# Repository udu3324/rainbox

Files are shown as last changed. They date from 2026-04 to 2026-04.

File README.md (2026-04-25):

# Rainbox - Ambient Rain Sound Generator

render3

An ambient sound device that is designed to fit on your nightstand. It is based on the esp32 and is super hackable.

* Makes variable rain with different sounds
* Helps with sleep disorders (insomnia, etc.)
* Creates a mist
* Wi-Fi controllable

## Purpose

Rain is something relaxing to listen to, and being able to hear it at night brings a greater quality to sleep. Not only does this have more features than those small rain devices seen on temu, this actually makes rain that is more audible and realistic, as well as coming with a bunch of more features.

## Zine Page
Some details have been redacted. DM me for the full version!
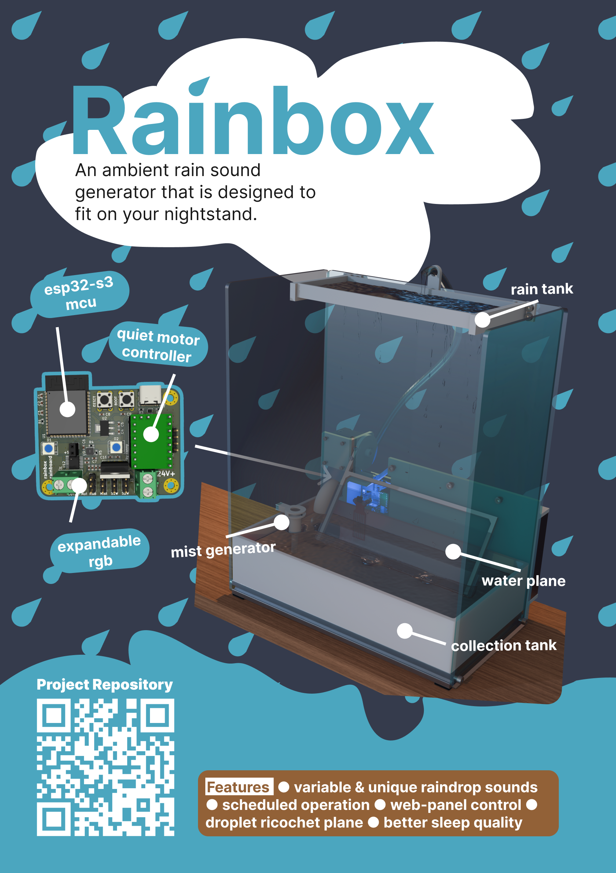
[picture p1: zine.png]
zine


## Webpanel Control

The Rainbox can be controlled through its webpanel that is hosted on its own AP or connected to WiFi.

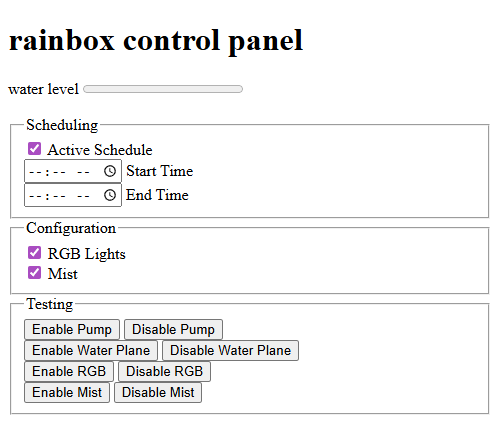
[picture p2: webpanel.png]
webpanel


## Mechanical Features

* Quiet submersed water pump that is speed controlled
* A water plane that makes water droplets ricochet off to make more unique noises
* Upper rain tank features hole diameters optimized for various water droplet sizes

### Stepper/Water Plane

A stepper motor directly controls the angle of a plastic/rubber sheet. It is a lightweight design that makes a alternative to where water droplets can land, and ultimately make more unique sounds. 

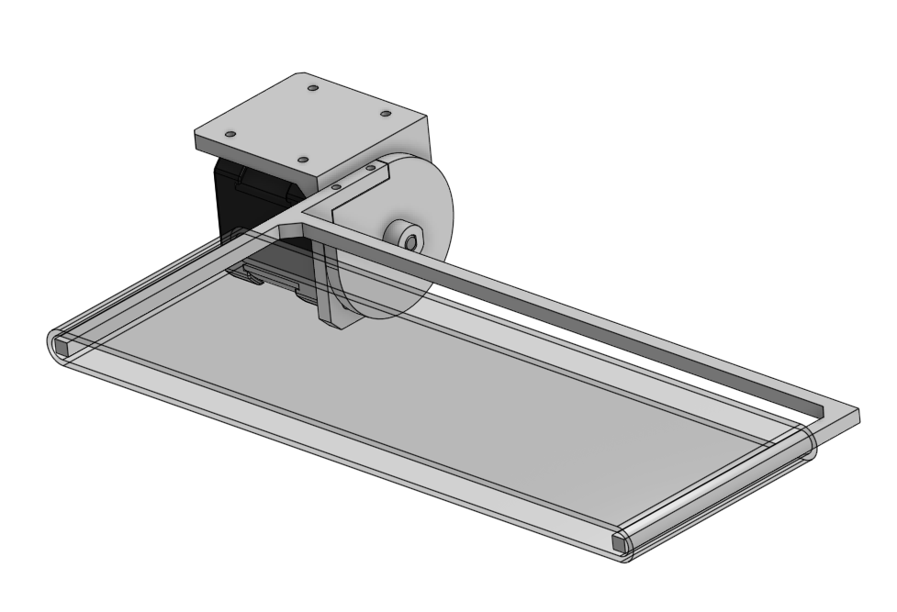
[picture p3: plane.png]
plane


### CAD

You can find the entire cad [here](https://cad.onshape.com/documents/e948a9a578129b2d9b3c44f2/w/f33f1e86b2b45cf8b68328c5/e/03b493761ac4f752afa24087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).

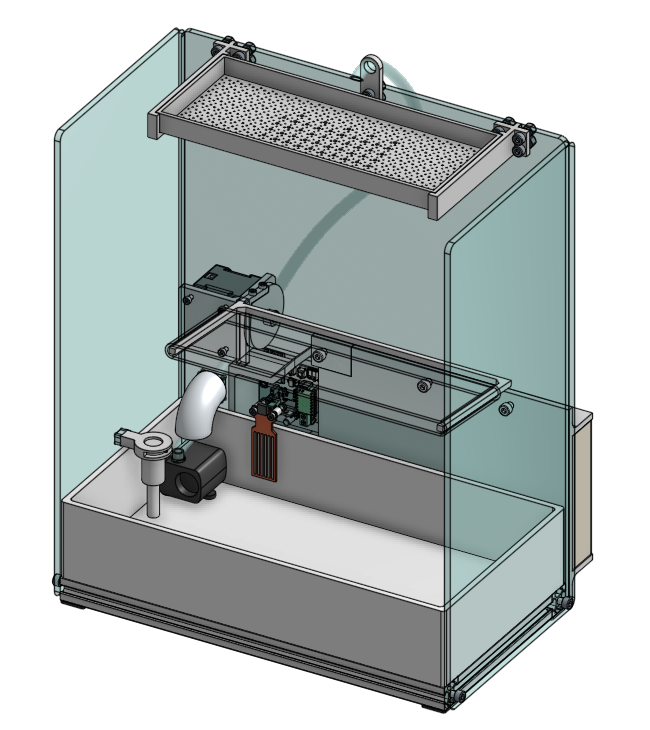
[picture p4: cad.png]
cad


## PCB Features

* Two RGB leds that can shine through the mist for ambience
* Can control a water atomizer to create mist
* Support for a external neopixel led strip
* Water level sensor support for closed loop control of the water pump
* TMC2240 stepper controller for StealthChop2™ support, making super quiet steps
* Super compact board with easy access to boot/reset buttons and usb-c

### Schematics

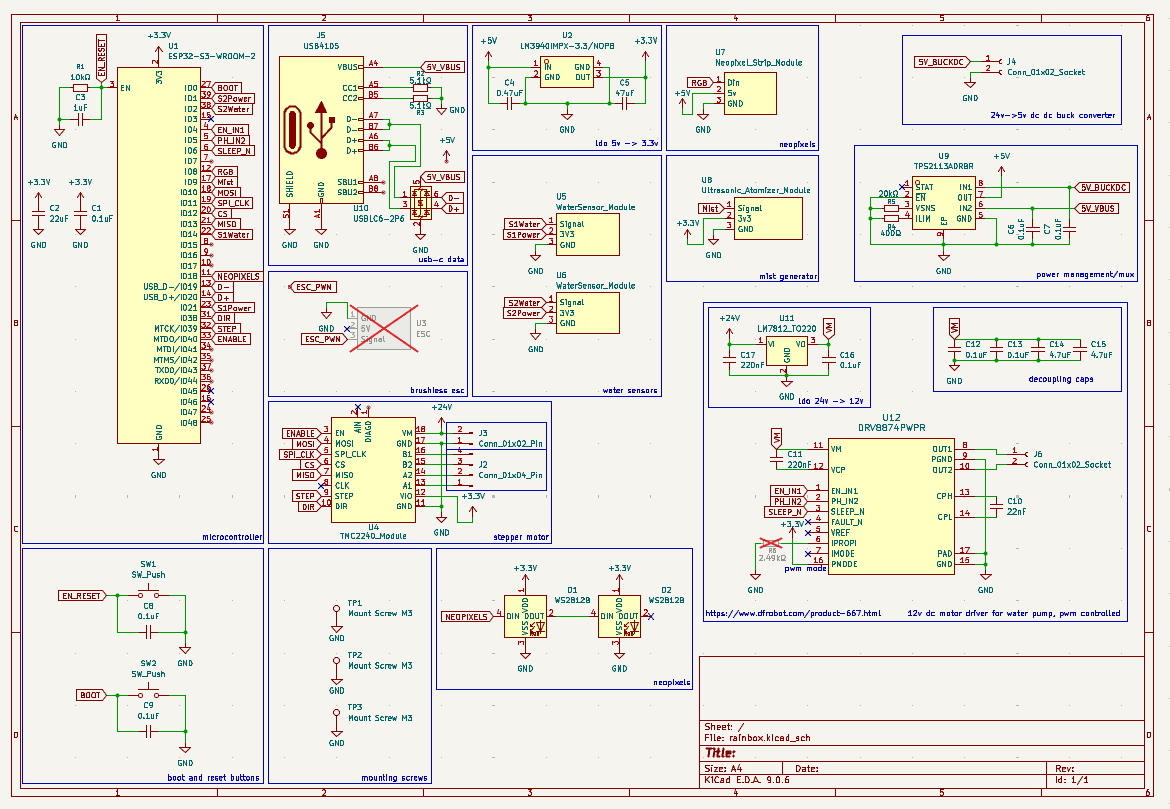
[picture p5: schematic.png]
schematic


### PCB

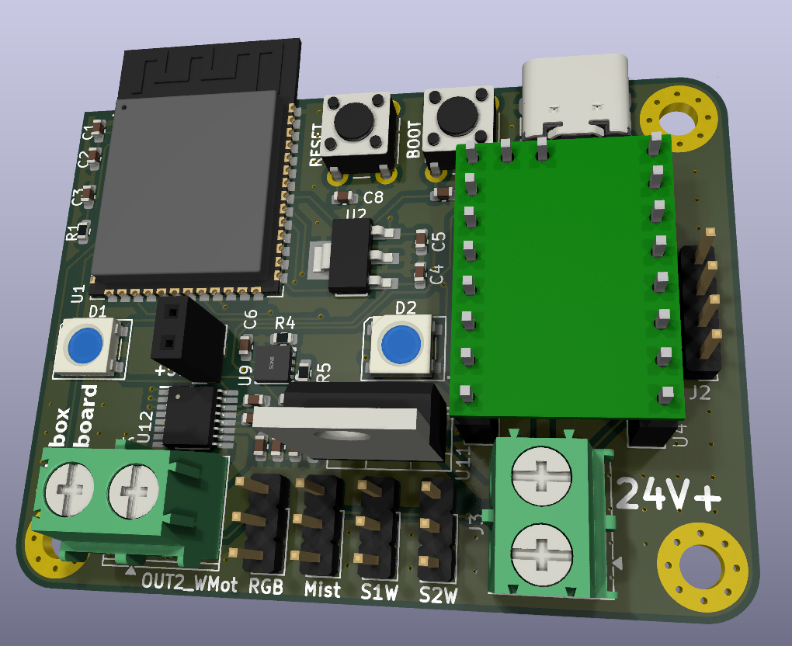
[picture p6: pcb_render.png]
pcb_render

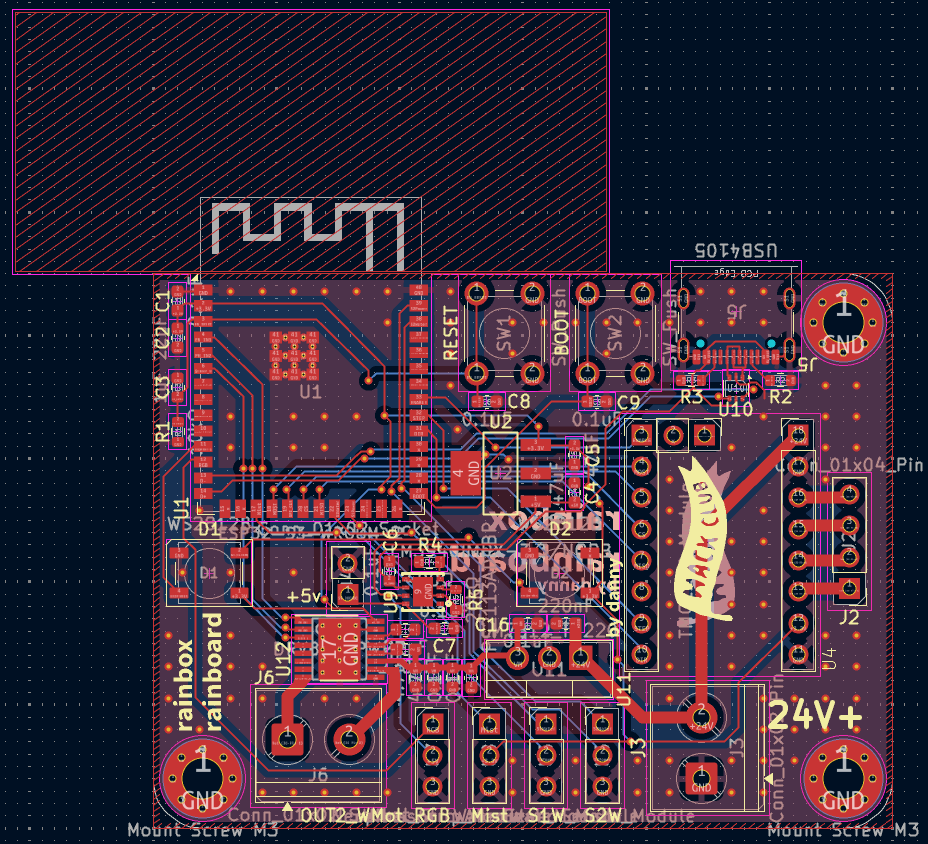
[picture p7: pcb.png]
pcb


## BOM

You can view the interactive BOM [here!](https://docs.google.com/spreadsheets/d/10gB80Lu2tYKqtstPC31-ZahqdRdbqbskEyKegbtCWHs/edit?usp=sharing) The total is around 150 USD.

### Build Steps
1. Get all the materials ready, 3d printed, and PCB fabricated
2. Cut out the polycarbonate on a CNC Mill
3. Tap the holes of the aluminum extrusion for M5 screws.
4. Assemble the bottom portion of the rainbox, which includes the bottom tank, aluminum extrusion, and polycarbonate walls
5. Screw the pcb onto the electronics cover
6. Connect all the motors, sensors, and water atomizer into the pcb
7. Mount all the electronics onto the back of the polycarbonate
8. Flash the firmware onto the board
9. Done! Control it through the WiFi AP web-panel

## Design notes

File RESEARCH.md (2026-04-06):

# rainbox research

## sound creation --- 

https://mynoise.net/NoiseMachines/rainNoiseGenerator.php
https://science.nasa.gov/earth/earth-observatory/listening-to-raindrops/

* water hitting directly on water (requires a depth of water)
* water hitting some sort of ground (tarp, or rubber)

### at what height? - 
water droplets hit their terminal velocity easily
~400mm

at what diameter of drop makes sound? what kind of sound? -
* 0.8/1.2mm dia - 13-25kHz direct water (high freq)
* 1.2/2.0 dia - quiet type
* 2.0/3.5mm dia - 1-10kHz direct water, 1-50kHz splat (low freq)

## fluid mechanics --- 

https://www.wisewell.com/blogs/news/is-deionized-water-the-same-as-distilled-water
use deionized water

focuses on creating these three diameter drops to create a dynamic sound of rain/weather

at least manage a ~2in deep water tank

water is brought from its bottom collecting tank to its upper tank, using a quiet motor with flaps 

based on the kohler rain shower head, a plate will guide water down holes using mainly gravity, not pressure

## electronics --- 

24v power supply

esp32-s3 (controls all)

### choice 1
https://zddcmotor.com/products/4245-brushless-motor (same)
https://www.aliexpress.us/item/3256807744943576.html
https://www.aliexpress.us/item/3256809335050730.html

### choice 2
https://www.underwaterthruster.com/products/3750-underwater-waterproof-and-corrosion-proof-brushless-motors-for-underwater-robots-and-rov-motors-for-unmanned-boats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
(get the esc from choice 1)
(also request them to waterproof/add cables free of charge)

brushless dc motor (preferably waterproof too but prioritize on quietness first)
brushless esc motor controller

nema 17 stepper motor
tmc2209/2240/2241 (prefer right to left) driver for quietness

https://www.aliexpress.us/item/3256806203259773.html
water level sensor (2x for top and bottom tank)

neopixel strip

https://www.aliexpress.us/item/3256809269681816.html
https://forum.arduino.cc/t/help-setting-25mm-ultrasonic-mist-maker/1333404
ultrasonic atomizer (m165d25, JHB20-17A384 or equivalent)
needs a driver controller of the same voltage and frequency

## frame/structure --- 

* tank/sides obviously has to be waterproof
* polycarbonate sides with a opening on one wall (maybe side cutouts too)
* bottom tank with a hole on the side, easy to clean and maintain
* 2020 aluminum extrusion for the frame and support
* petg prints preferred for everything
* petg or pvc flexible clear tubing

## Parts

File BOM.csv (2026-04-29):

Part | Description | URL | URL Note | Price (USD) (raw) | URL (Alt) | Price (Alt) (USD) | URL Note (Alt) | Quantity (per unit) | Sourcing | Subtotals
185x400 Polycarbonate | 5mm thick | https://clearambershop.com/en-us/products/axgard-clear-5mm-uv-protected-glazing-sheet | in the uk | 40.55 | https://www.lowes.com/pd/Professional-Plastics-Clear-Polycarbonate-Sheet-3-16TX48WX48L/7134359 | 78.9 | its double the size needed, cant find a smaller one :( | 2 | Need to buy | 78.9
330x400 Polycarb sheet | ~ | https://clearambershop.com/en-us/products/axgard-clear-5mm-uv-protected-glazing-sheet |  | 20 | not needed |  |  | 1 | Need to buy
330mm 2020 aluminum extrusion |  | https://www.zyltech.com/aluminum-extrusion-custom-cut-service/ |  | 2.26 |  |  |  | 2 | Already have | 4.52
140mm 2020 aluminum extrusion |  | ~ |  | 2.26 |  |  |  | 2 | Need to buy | 4.52
300x80mm Plastic/rubber sheet | i'll just upcycle some trash |  |  |  |  |  |  | 1 | Already have
Anti-slip rubber pad adhesive | 20x20mm squares | https://www.aliexpress.us/item/3256807696141646.html |  | 1 |  |  |  | 4 | Already have | 4
 |  |  |  |  |  |  |  |  |  | 91.94 | Frame Subtotal
Bottom (water) tank | 3d print (large) |  |  |  |  |  |  | 1 | Self-print
Surface fork holder | ~ |  |  |  |  |  |  | 1 | Self-print
Gear | ~ |  |  |  |  |  |  | 1 | Self-print
Tube guide | ~ |  |  |  |  |  |  | 1 | Self-print
Motor mount | ~ |  |  |  |  |  |  | 1 | Self-print
Power supply mount | ~ |  |  |  |  |  |  | 1 | Self-print
Electronics cover | ~ |  |  |  |  |  |  | 1 | Self-print
Water atomizer mount | ~ |  |  |  |  |  |  | 1 | Self-print
Rain tank | ~ (large) |  |  |  |  |  |  | 1 | Self-print
Rain tank holder | ~ |  |  |  |  |  |  | 1 | Self-print
Rain tank holder 2 | ~ |  |  |  |  |  |  | 1 | Self-print
Top tube holder | ~ |  |  |  |  |  |  | 1 | Self-print
Spacer | ~ |  |  |  |  |  |  | 2 | Self-print
 |  |  |  |  |  |  |  |  |  | 0 | 3D-Print Subtotal
Water sensor | generic | https://www.aliexpress.us/item/3256806203259773.html |  | 1.01 |  |  |  | 1 | Need to buy | 1.01
Water atomizer | includes wick & control board | https://www.aliexpress.us/item/3256809269681816.html |  | 1.3 |  |  |  | 1 | Need to buy | 1.3
Water pump (350L/H) | generic, includes tube | https://www.dfrobot.com/product-667.html |  | 9.2 |  |  |  | 1 | Need to buy | 9.2
Nema 17 40mm stepper motor | 4 pin 2.54 pitch | https://www.omc-stepperonline.com/nema-17-bipolar-0-9deg-36ncm-51oz-in-0-9a-5-4v-42x42x40mm-4-wires-17hm15-0904s |  | 12.05 |  |  |  | 1 | Already have | 12.05
AC Plug (inlet, 719W-UEL3BR51) | c13 | https://www.digikey.com/en/products/detail/qualtek/719W-UEL3BR51/23019206 |  | 6.7 |  |  |  | 1 | Already have | 6.7
C13 AC Power Cord | generic, monitor cable | ? |  |  |  |  |  | 1 | Already have
24v Power Supply | LRS-350-24 | https://meanwell-ps.com/products/lrs-350-24 |  | 31.4 |  |  |  | 1 | Already have | 31.4
 |  |  |  |  |  |  |  |  |  | 61.66 | Electronics Subtotal
M5x0.8x16mm cap screw | stainless steel, no rust | https://www.mcmaster.com/91292A126/ | packs of 100 | 14.86 | https://detail.tmall.com/item.htm?id=722759297726 | 1.14 |  | 23 | Need to buy | 1.14
M5x0.8 Nylon lock nut | ~ | https://www.mcmaster.com/94205A240/ | packs of 50 | 8 | https://detail.tmall.com/item.htm?id=556902193652 | 0.63 |  | 13 | Need to buy | 0.63
M4x0.7x8mm cap screw | ~ (for power supply mount) | https://www.mcmaster.com/91292A108/ | packs of 100 | 8.91 | https://detail.tmall.com/item.htm?id=722759297726 | 0.6 |  | 4 | Need to buy | 0.6
M3x0.5x16mm cap screw | ~ | https://www.mcmaster.com/91292A115/ | packs of 100 | 7.73 | ~ | 0.54 |  | 2 | Need to buy | 0.54
M3x0.5x12mm cap screw | ~ | https://www.mcmaster.com/91292A114/ | packs of 100 | 6.54 | ~ | 0.89 |  | 4 | Need to buy | 0.89
M3x0.5x8mm cap screw | ~ | https://www.mcmaster.com/91292A112/ | packs of 100 | 5.94 | ~ | 0.8 |  | 6 | Need to buy | 0.8
M3x0.5x6mm cap screw | ~ | https://www.mcmaster.com/91292A111/ | packs of 100 | 12.71 | ~ | 0.69 |  | 3 | Need to buy | 0.69
M3x0.5x4mm cap screw | ~ (for gear shaft lock) | https://www.mcmaster.com/91292A109/ | packs of 50 | 3.86 | ~ | 0.71 |  | 1 | Need to buy | 0.71
M3 nylon lock nuts | ~ (or thin ones) | https://www.mcmaster.com/94205A220/ | packs of 50 | 6.52 | https://detail.tmall.com/item.htm?id=556902193652 | 0.55 |  | 6 | Need to buy | 0.55
2020 frame T-slot nuts | generic | https://www.pcboard.ca/sliding-t-slot-nut | packs of 5 | 0.78 |  |  |  | 4 | Already have | 3.12
 |  |  |  |  |  |  |  |  |  | 9.67 | Fasteners Subtotal
TMC2240 Module | plugs into pcb | https://biqu.equipment/products/bigtreetech-tmc2240-v1-0 |  | 11 |  |  |  | 1 | Need to buy | 11
WS2182B | neopixel | https://www.digikey.com/en/products/detail/sparkfun-electronics/COM-24837/22321085 |  | 0.85 |  |  |  | 2 | Need to buy | 1.7
Screw Terminal Block | 5mm pitch | https://www.digikey.com/en/products/detail/phoenix-contact/1935161/568614 |  | 1.07 |  |  |  | 2 | Need to buy | 2.14
2 Row Pin Socket | 2.54 pitch | https://www.digikey.com/en/products/detail/preci-dip/801-87-002-10-001101/3757429 |  | 0.33 |  |  |  | 2 | Need to buy | 0.66
8 Row Pin Socket | ~ | https://www.digikey.com/en/products/detail/preci-dip/801-87-008-10-001101/3757440 |  | 1.04 |  |  |  | 2 | Need to buy | 2.08
3 Row Pin Header | ~ | https://www.digikey.com/en/products/detail/w%C3%BCrth-elektronik/61300311121/4846825 |  | 0.13 |  |  |  | 4 | Already have | 0.52
4 Row Pin Header | ~ | https://www.digikey.com/en/products/detail/w%C3%BCrth-elektronik/61300411121/4846827 |  | 0.19 |  |  |  | 1 | Already have | 0.19
6mm Tactile Switch Button |  | https://www.digikey.com/en/products/detail/schurter-inc/1301-9301/7602711 |  | 0.58 |  |  |  | 2 | Already have | 1.16
LM7812 | 24v to 12v | https://www.digikey.com/en/products/detail/texas-instruments/LM7812CT-NOPB/3901975 |  | 1.8 |  |  |  | 1 | Need to buy | 1.8
ESP32-S3-Wroom-2 |  | https://www.digikey.com/en/products/detail/espressif-systems/ESP32-S3-WROOM-2-N32R16V/25811280 |  | 11.44 |  |  |  | 1 | Need to buy | 11.44
0.1uF | 0603 ceramic capacitor | https://www.digikey.com/en/products/detail/murata-electronics/GRM033R60J104KE19D/702433 |  | 0.1 |  |  |  | 8 | Need to buy | 0.8
22nF | ~ | https://www.digikey.com/en/products/detail/samsung-electro-mechanics/CL10B223KO8WPNC/20498563 |  | 0.1 |  |  |  | 1 | Need to buy | 0.1
220nF | ~ | https://www.digikey.com/en/products/detail/samsung-electro-mechanics/CL10E224KA84PNC/20498501 |  | 0.17 |  |  |  | 2 | Need to buy | 0.34
4.7uF | ~ | https://www.digikey.com/en/products/detail/samsung-electro-mechanics/CL10A475KP8NNNC/3886702 |  | 0.1 |  |  |  | 2 | Need to buy | 0.2
22uF | ~ | https://www.digikey.com/en/products/detail/murata-electronics/GRM188R60G226MEA0D/2334877 |  | 0.13 |  |  |  | 1 | Need to buy | 0.13
1uF | ~ | https://www.digikey.com/en/products/detail/murata-electronics/GRM033R60J105MEA2D/4213369 |  | 0.1 |  |  |  | 1 | Need to buy | 0.1
0.47uF | ~ | https://www.digikey.com/en/products/detail/murata-electronics/GRM033R60J474KE90D/5027494 |  | 0.1 |  |  |  | 1 | Need to buy | 0.1
47uF | ~ | https://www.digikey.com/en/products/detail/murata-electronics/GRM188R60G476ME01D/13996897 |  | 0.35 |  |  |  | 1 | Need to buy | 0.35
USB4105 | usb c component | https://www.digikey.com/en/products/detail/gct/USB4105-GF-A/11198441 |  | 0.8 |  |  |  | 1 | Need to buy | 0.8
10kΩ | 0603 resistor | https://www.digikey.com/en/products/detail/yageo/RC0603FR-0710KL/726880 |  | 0.1 |  |  |  | 1 | Need to buy | 0.1
5.1kΩ | ~ | https://www.digikey.com/en/products/detail/yageo/RC0603FR-075K1L/727268 |  | 0.1 |  |  |  | 2 | Need to buy | 0.2
400Ω | ~ | https://www.digikey.com/en/products/detail/vishay-dale-thin-film/PAT0603E4000BST1/2278871 |  | 0.75 |  |  |  | 1 | Need to buy | 0.75
20kΩ | ~ | https://www.digikey.com/en/products/detail/yageo/RC0603FR-0720KL/727040 |  | 0.1 |  |  |  | 1 | Need to buy | 0.1
USBLC6-2P6 | usb esd protection ic | https://www.digikey.com/en/products/detail/stmicroelectronics/USBLC6-2P6/1007440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 |  | 0.65 |  |  |  | 1 | Need to buy | 0.65
DRV8874PWPR | dc motor controller | https://www.digikey.com/en/products/detail/texas-instruments/DRV8874PWPR/11502339 |  | 3.12 |  |  |  | 1 | Need to buy | 3.12
LM3940IMPX-3.3/NOPB | ldo 5v to 3v3 | https://www.digikey.com/en/products/detail/texas-instruments/LM3940IMPX-3-3-NOPB/367097 |  | 1.73 |  |  |  | 1 | Need to buy | 1.73
TPS2113ADRBR | power management ic | https://www.digikey.com/en/products/detail/texas-instruments/TPS2113ADRBR/2353703 |  | 2.35 |  |  |  | 1 | Need to buy | 2.35
 |  |  |  |  |  |  |  |  |  | 44.61 | Components Subtotal
PCB | JLCPCB PCB only service |  |  | 7.12 |  |  |  | 1 | Need to buy | 7.12
 |  |  |  |  |  |  |  |  |  | 7.12 | PCB Subtotal
 |  |  |  |  |  |  |  |  |  | 215 | TOTAL
 |  |  |  |  |  |  |  |  |  | 151 | TOTAL without things i already have

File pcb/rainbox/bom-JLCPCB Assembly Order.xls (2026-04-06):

JLCPCB BOM Tool - BOM Matching
BOM name：bom-JLCPCB Assembly Order.xlsx |  |  | Download Time：2026-04-05 12:07:02 |  |  |  | * Our matching results are updated in real-time, but stock and prices may change. If it's been over 24 hours, please re-match before placing your order.
PCB Assembled Qty：5 |  |  | Est. Total Price：12.9028
Your BOM |  |  |  |  | Matched Parts |  |  |  |  |  |  | Order Information
Top Designator | Bottom Designator | Comment | Footprint | JLCPCB Part # | Matches | Part # | Manufacturer | Footprint | Description | Category | Warning | JLCPCB Part # | Product link | Lib Type | Qty | Source | Total Price ($)
C1,C12,C13,C16,C6,C7,C8,C9 |  | 0.1uF | 0603 |  | Unconfirmed | CC0603KRX7R9BB104 | YAGEO | 0603 | 100nF 50V X7R ±10% 0603 Multilayer Ceramic Capacitors MLCC - SMD/SMT ROHS | Multilayer Ceramic Capacitors MLCC - SMD/SMT | 1.The comment (CC0603KRX7R9BB104) of this part does not match the one (0.1uF) provided in your BOM. Please confirm; | C14663 | https://jlcpcb.com/partdetail/YAGEO-CC0603KRX7R9BB104/C14663 | Basic | 16 | 16 JLCPCB | 0.0496
C2 |  | 22uF | 0603 |  | Select by System | CL10A226MQ8NRNC | Samsung Electro-Mechanics | 0603 | 22uF 6.3V X5R ±20% 0603 Multilayer Ceramic Capacitors MLCC - SMD/SMT ROHS | Multilayer Ceramic Capacitors MLCC - SMD/SMT |  | C59461 | https://jlcpcb.com/partdetail/60514-CL10A226MQ8NRNC/C59461 | Basic | 2 | 2 JLCPCB | 0.0188
C3 |  | 1uF | 0603 |  | Select by System | CL10A105KB8NNNC | Samsung Electro-Mechanics | 0603 | 1uF 50V X5R ±10% 0603 Multilayer Ceramic Capacitors MLCC - SMD/SMT ROHS | Multilayer Ceramic Capacitors MLCC - SMD/SMT |  | C15849 | https://jlcpcb.com/partdetail/16531-CL10A105KB8NNNC/C15849 | Basic | 2 | 2 JLCPCB | 0.0154
C4 |  | 0.47uF | 0603 |  | Unconfirmed | CL10B474KA8NNNC | Samsung Electro-Mechanics | 0603 | 25V 470nF X7R ±10% 0603 Multilayer Ceramic Capacitors MLCC - SMD/SMT ROHS | Multilayer Ceramic Capacitors MLCC - SMD/SMT | 1.The comment (CL10B474KA8NNNC) of this part does not match the one (0.47uF) provided in your BOM. Please confirm; | C1623 | https://jlcpcb.com/partdetail/1975-CL10B474KA8NNNC/C1623 | Basic | 2 | 2 JLCPCB | 0.013
C5 |  | 47uF | 0603 |  | Select by System | GRM188R60J476ME15D | Murata Electronics | 0603 | 47uF 6.3V X5R ±20% 0603 Multilayer Ceramic Capacitors MLCC - SMD/SMT ROHS | Multilayer Ceramic Capacitors MLCC - SMD/SMT |  | C140782 | https://jlcpcb.com/partdetail/152108-GRM188R60J476ME15D/C140782 | Extended | 6 | 6 JLCPCB | 0.3702
C10 |  | 22nF | 0603 |  | Select by System | CL10B223KB8NNNC | Samsung Electro-Mechanics | 0603 | 22nF 50V X7R ±10% 0603 Multilayer Ceramic Capacitors MLCC - SMD/SMT ROHS | Multilayer Ceramic Capacitors MLCC - SMD/SMT |  | C21122 | https://jlcpcb.com/partdetail/21834-CL10B223KB8NNNC/C21122 | Basic | 2 | 2 JLCPCB | 0.0084
C11,C17 |  | 220nF | 0603 |  | Select by System | CL10B224KA8NNNC | Samsung Electro-Mechanics | 0603 | 220nF 25V X7R ±10% 0603 Multilayer Ceramic Capacitors MLCC - SMD/SMT ROHS | Multilayer Ceramic Capacitors MLCC - SMD/SMT |  | C21120 | https://jlcpcb.com/partdetail/21832-CL10B224KA8NNNC/C21120 | Basic | 4 | 4 JLCPCB | 0.03
C14,C15 |  | 4.7uF | 0603 |  | Select by System | CL10A475KO8NNNC | Samsung Electro-Mechanics | 0603 | 16V 4.7uF X5R ±10% 0603 Multilayer Ceramic Capacitors MLCC - SMD/SMT ROHS | Multilayer Ceramic Capacitors MLCC - SMD/SMT |  | C19666 | https://jlcpcb.com/partdetail/20375-CL10A475KO8NNNC/C19666 | Basic | 4 | 4 JLCPCB | 0.0412
J5 |  | USB4105 | USB_C_Receptacle_GCT_USB4105-xx-A_16P_TopMnt_Horizontal |  | Select by System | USB4105-GF-A-060 | Global Connector Technology | SMD | -40℃~+85℃ 1 12P 48V 5A Black Female Surface Mount, Right Angle Type-C USB 2.0 SMD USB Connectors ROHS | USB Connectors |  | C3025063 | https://jlcpcb.com/partdetail/3554049-USB4105_GF_A060/C3025063 | Extended | 2 | 2 JLCPCB | 2.3648
R1 |  | 10kΩ | 0603 |  | Select by System | 0603WAF1002T5E | UNI-ROYAL(Uniroyal Elec) | 0603 | -55℃~+155℃ 100mW 10kΩ 75V Thick Film Resistor ±1% ±100ppm/℃ 0603 Chip Resistor - Surface Mount ROHS | Chip Resistor - Surface Mount |  | C25804 | https://jlcpcb.com/partdetail/26547-0603WAF1002T5E/C25804 | Basic | 2 | 2 JLCPCB | 0.0026
R2,R3 |  | 5.1kΩ | 0603 |  | Select by System | 0603WAF5101T5E | UNI-ROYAL(Uniroyal Elec) | 0603 | -55℃~+155℃ 100mW 5.1kΩ 75V Thick Film Resistor ±1% ±100ppm/℃ 0603 Chip Resistor - Surface Mount ROHS | Chip Resistor - Surface Mount |  | C23186 | https://jlcpcb.com/partdetail/23913-0603WAF5101T5E/C23186 | Basic | 4 | 4 JLCPCB | 0.0056
R4 |  | 400Ω | 0603 |  | Select by System | PAT0603E4000BST1 | Vishay Intertech | 0603 | -55℃~+155℃ 150mW 400Ω Thin Film Resistor ±0.1% ±25ppm/℃ 0603 Chip Resistor - Surface Mount ROHS | Chip Resistor - Surface Mount |  | C5841024 | https://jlcpcb.com/partdetail/VishayIntertech-PAT0603E4000BST1/C5841024 | Extended | 2 | 2 JLCPCB | 2.3806
R5 |  | 20kΩ | 0603 |  | Select by System | 0603WAF2002T5E | UNI-ROYAL(Uniroyal Elec) | 0603 | -55℃~+155℃ 100mW 20kΩ 75V Thick Film Resistor ±1% ±100ppm/℃ 0603 Chip Resistor - Surface Mount ROHS | Chip Resistor - Surface Mount |  | C4184 | https://jlcpcb.com/partdetail/4591-0603WAF2002T5E/C4184 | Basic | 2 | 2 JLCPCB | 0.0024
U2 |  | LM3940IMPX-3.3/NOPB | SOT-223-4_L6.5-W3.5-P2.30-LS7.0-BR |  | Select by System | LM3940IMPX-3.3/NOPB | Texas Instruments | SOT-223-4 | -40℃~+125℃ 1 110mA 150uVrms 1A 200mV@(100mA) 3.3V 7.5V Fixed Over Temperature Protection、Short Circuit Protection Positive SOT-223-4 Voltage Regulators - Linear, Low Drop Out (LDO) Regulators ROHS | Voltage Regulators - Linear, Low Drop Out (LDO) Regulators |  | C544820 | https://jlcpcb.com/partdetail/TexasInstruments-LM3940IMPX_3_3NOPB/C544820 | Extended | 2 | 2 JLCPCB | 2.761
U9 |  | TPS2113ADRBR | SON-8_L3.0-W3.0-P0.65-LS3.0-BL-EP |  | Select by System | TPS2113ADRBR | Texas Instruments | SON-8(3x3) | -40℃~+125℃ 2.8V~5.5V 2A 84mΩ Overcurrent Protection(OCP)、Over Temperature Protection SON-8(3x3) Power Distribution Switches ROHS | AC-DC Controllers And Regulators |  | C354512 | https://jlcpcb.com/partdetail/TexasInstruments-TPS2113ADRBR/C354512 | Extended | 2 | 2 JLCPCB | 1.8608
U10 |  | USBLC6-2P6 | SOT-666 |  | Select by System | USBLC6-2P6 | STMicroelectronics | SOT-666-6 | -40℃~+125℃ 150nA 17V 2 3.5pF 5.25V 5A@8/20us 6V ESD IEC 61000-4-2 Unidirectional SOT-666-6 ESD and Surge Protection (TVS/ESD) ROHS | ESD And Surge Protection (TVS/ESD) |  | C15999 | https://jlcpcb.com/partdetail/STMicroelectronics-USBLC62P6/C15999 | Extended | 5 | 5 JLCPCB | 1.219
U12 |  | DRV8874PWPR | PWP0016J_N |  | Select by System | DRV8874PWPR | Texas Instruments | HTSSOP-16-EP | -40℃~+125℃ 1 200mΩ 750nA 9A Yes HTSSOP-16-EP Brushed DC Motor Drivers ROHS | Brushed DC Motor Drivers |  | C1855818 | https://jlcpcb.com/partdetail/TexasInstruments-DRV8874PWPR/C1855818 | Extended | 2 | 2 JLCPCB | 1.7594
U1 |  | ESP32-S3-WROOM-2 | ESP32-S3-WROOM-2 |  | Unconfirmed | ESP32-S3-WROOM-2-N32R16V | Espressif Systems | SMD | -103.5dBm -40℃~+65℃ 2.4GHz 20.5dBm 355mA 3V~3.6V 95mA Bluetooth5.0 ESP32-S3R16V On-board PCB Antenna UART、SDIO、SPI、I2C、I2S、USB SMD WiFi Modules ROHS | WiFi Modules | 1.The comment (ESP32-S3-WROOM-2-N32R16V) of this part does not match the one (ESP32-S3-WROOM-2) provided in your BOM. Please confirm; | C42417293 | https://jlcpcb.com/partdetail/44421476-ESP32_S3_WROOM_2N32R16V/C42417293 | Extended | 2 | 0 JLCPCB | 0
D1,D2 |  | WS2812B | LED_WS2812B_PLCC4_5.0x5.0mm_P3.2mm |  | Unconfirmed | WS2812B-B/W |  |  | 0.6mA 1.57mm 2kHz 3.7V~5.3V 5.4mm 5mm 800Kbit/s B:465nm~475nm、R:620nm~630nm、G:515nm~525nm G:600mcd~1000mcd、B:200mcd~300mcd、R:300mcd~500mcd 内置上电复位电路、内置掉电复位电路、内置单向传输功能 SMD5050-4P RGB LEDs(Built-in IC) ROHS |  | 1.The comment (WS2812B-B/W) of this part does not match the one (WS2812B) provided in your BOM. Please confirm; |  |  | Extended | 0 | 0 JLCPCB | 0
J2 |  | Conn_01x04_Pin | PinHeader_1x04_P2.54mm_Vertical |  | No matches | No Part Selected
J3 |  | Conn_01x02_Pin | TerminalBlock_Phoenix_PT-1,5-2-5.0-H_1x02_P5.00mm_Horizontal |  | No matches | No Part Selected
J4 |  | Conn_01x02_Socket | PinSocket_1x02_P2.54mm_Vertical |  | No matches | No Part Selected
J6 |  | Conn_01x02_Socket | TerminalBlock_Phoenix_PT-1,5-2-5.0-H_1x02_P5.00mm_Horizontal |  | No matches | No Part Selected
SW1,SW2 |  | SW_Push | SW_PUSH_6mm |  | No matches | No Part Selected
U4 |  | TMC2240_Module | tmc2240_module |  | No matches | No Part Selected
U5,U6 |  | WaterSensor_Module | PinHeader_1x03_P2.54mm_Vertical |  | No matches | No Part Selected
U7 |  | Neopixel_Strip_Module | PinHeader_1x03_P2.54mm_Vertical |  | No matches | No Part Selected
U8 |  | Ultrasonic_Atomizer_Module | PinHeader_1x03_P2.54mm_Vertical |  | No matches | No Part Selected
U11 |  | LM7812_TO220 | TO-220-3_Vertical |  | No matches | No Part Selected

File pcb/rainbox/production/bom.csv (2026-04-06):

Designator | Footprint | Quantity | Value | LCSC Part #
C1, C12, C13, C16, C6, C7, C8, C9 | 0603 | 8 | 0.1uF
C10 | 0603 | 1 | 22nF
C11, C17 | 0603 | 2 | 220nF
C14, C15 | 0603 | 2 | 4.7uF
C2 | 0603 | 1 | 22uF
C3 | 0603 | 1 | 1uF
C4 | 0603 | 1 | 0.47uF
C5 | 0603 | 1 | 47uF
D1, D2 | LED_WS2812B_PLCC4_5.0x5.0mm_P3.2mm | 2 | WS2812B
J2 | PinHeader_1x04_P2.54mm_Vertical | 1 | Conn_01x04_Pin
J3 | TerminalBlock_Phoenix_PT-1,5-2-5.0-H_1x02_P5.00mm_Horizontal | 1 | Conn_01x02_Pin
J4 | PinSocket_1x02_P2.54mm_Vertical | 1 | Conn_01x02_Socket
J5 | USB_C_Receptacle_GCT_USB4105-xx-A_16P_TopMnt_Horizontal | 1 | USB4105
J6 | TerminalBlock_Phoenix_PT-1,5-2-5.0-H_1x02_P5.00mm_Horizontal | 1 | Conn_01x02_Socket
R1 | 0603 | 1 | 10kΩ
R2, R3 | 0603 | 2 | 5.1kΩ
R4 | 0603 | 1 | 400Ω
R5 | 0603 | 1 | 20kΩ
SW1, SW2 | SW_PUSH_6mm | 2 | SW_Push
TP1, TP2, TP3 | MountingHole_3.2mm_M3_Pad_Via | 3 | Mount Screw M3
U1 | ESP32-S3-WROOM-2 | 1 | ESP32-S3-WROOM-2
U10 | SOT-666 | 1 | USBLC6-2P6
U11 | TO-220-3_Vertical | 1 | LM7812_TO220
U12 | PWP0016J_N | 1 | DRV8874PWPR
U2 | SOT-223-4_L6.5-W3.5-P2.30-LS7.0-BR | 1 | LM3940IMPX-3.3/NOPB | C544820
U4 | tmc2240_module | 1 | TMC2240_Module
U5, U6 | PinHeader_1x03_P2.54mm_Vertical | 2 | WaterSensor_Module
U7 | PinHeader_1x03_P2.54mm_Vertical | 1 | Neopixel_Strip_Module
U8 | PinHeader_1x03_P2.54mm_Vertical | 1 | Ultrasonic_Atomizer_Module
U9 | SON-8_L3.0-W3.0-P0.65-LS3.0-BL-EP | 1 | TPS2113ADRBR | C354512

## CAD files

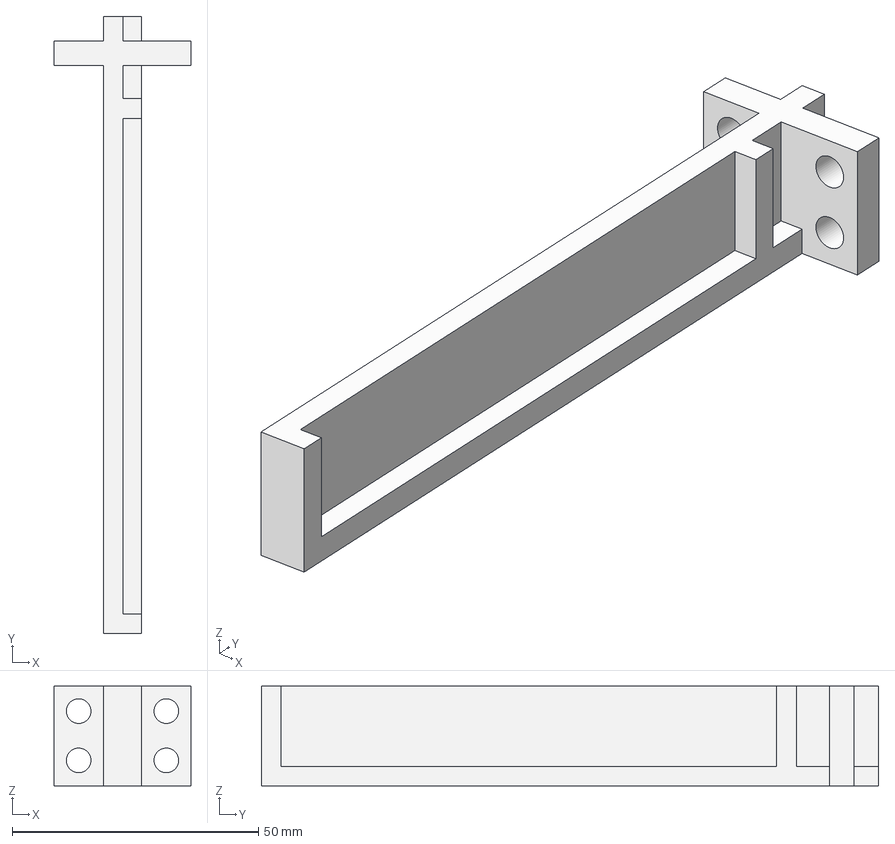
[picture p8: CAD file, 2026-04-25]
cad/Full Assembly - Rain Tank Holder.step
27.8 x 125.3 x 20.3 mm

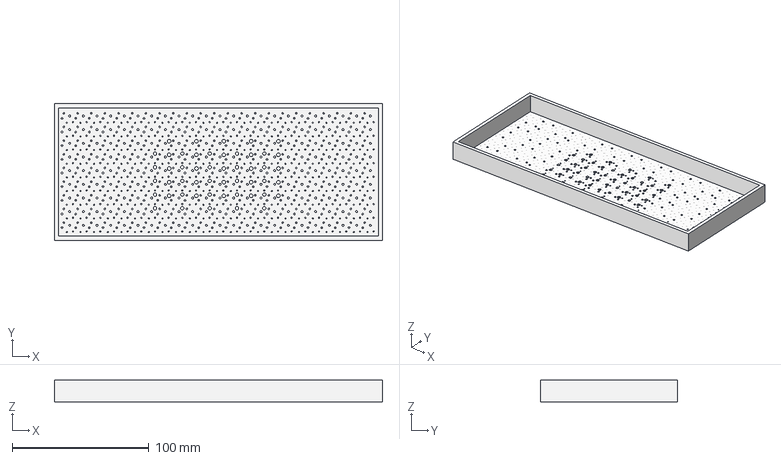
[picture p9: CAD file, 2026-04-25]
cad/Full Assembly - Rain Tank.step
240.0 x 100.0 x 16.0 mm

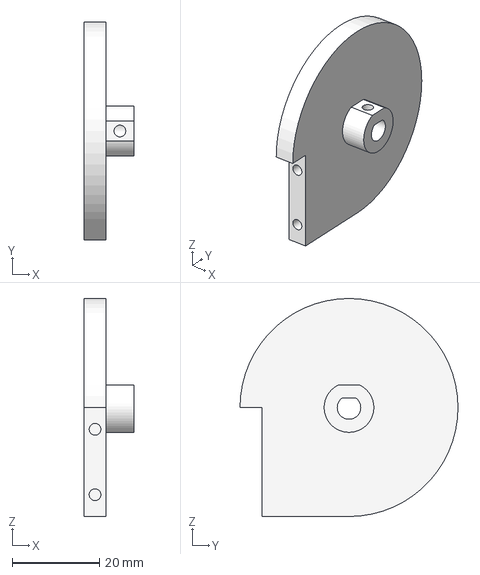
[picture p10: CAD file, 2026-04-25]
cad/Full Assembly - Gear.step
11.4 x 50.0 x 50.0 mm

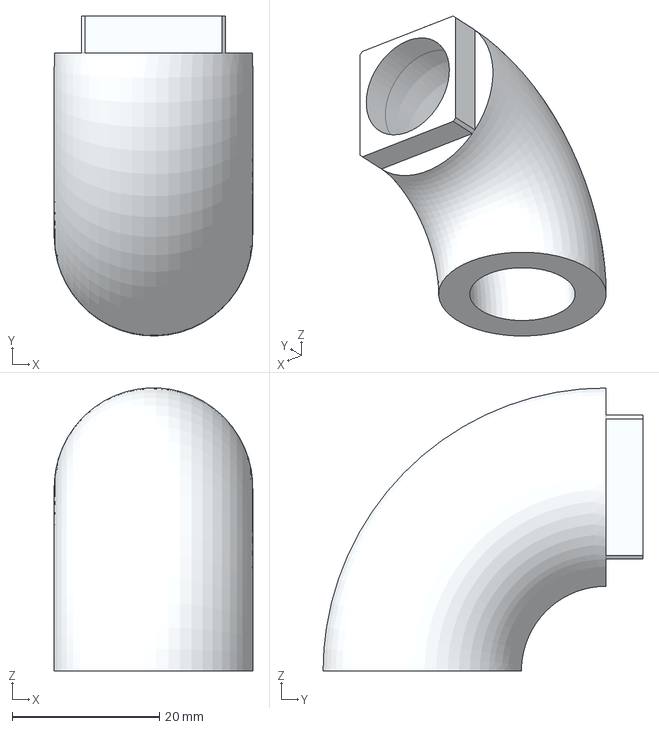
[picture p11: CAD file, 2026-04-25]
cad/Full Assembly - Tube Guide.step
27.0 x 43.5 x 38.5 mm

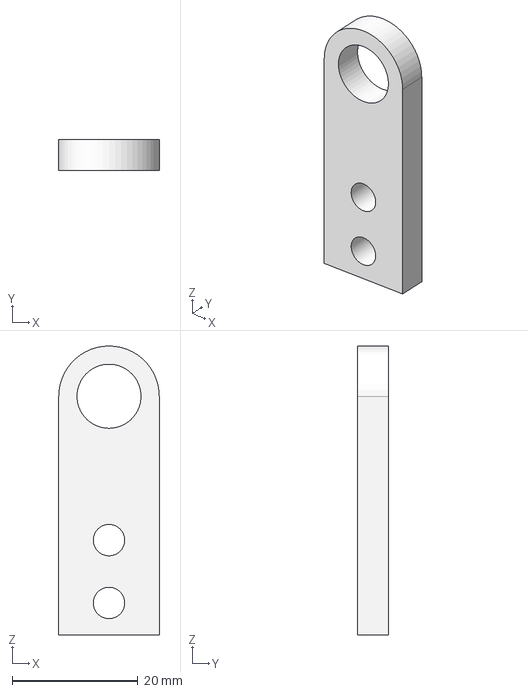
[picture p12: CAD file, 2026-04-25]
cad/Full Assembly - top tube holder.step
16.0 x 5.00 x 46.0 mm

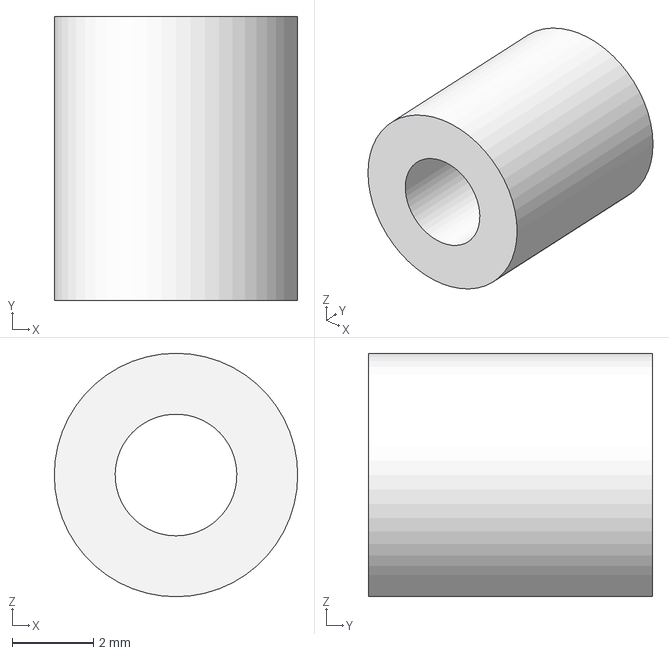
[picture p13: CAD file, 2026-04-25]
cad/Full Assembly - Spacer.step
6.00 x 7.00 x 6.00 mm

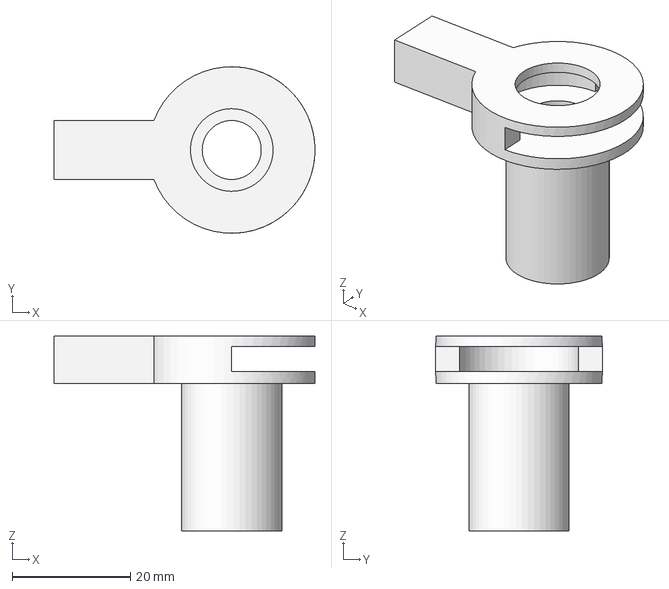
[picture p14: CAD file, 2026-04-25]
cad/Full Assembly - Water Atomizer Mount.step
44.2 x 28.2 x 33.0 mm

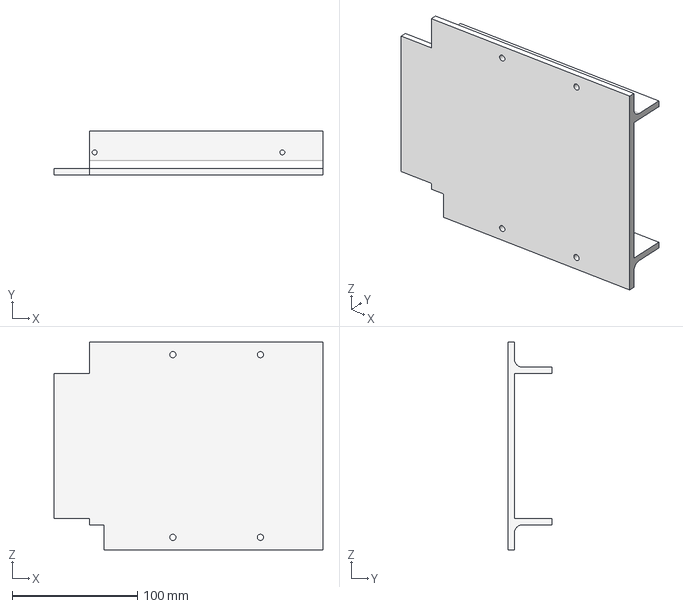
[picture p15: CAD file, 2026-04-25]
cad/Full Assembly - Power Supply Mount.step
215.0 x 35.0 x 166.0 mm

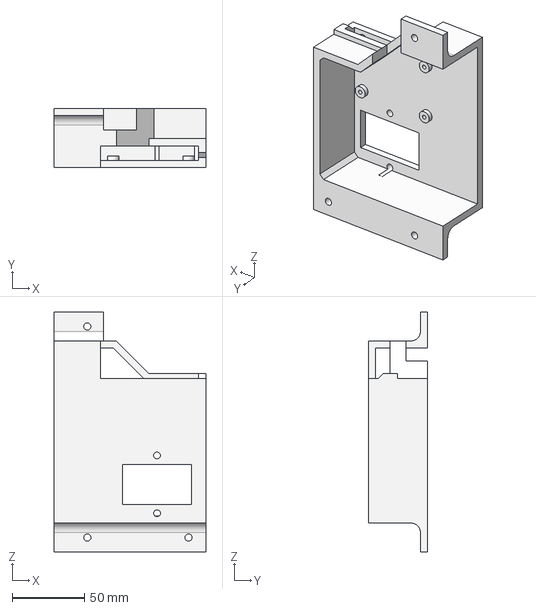
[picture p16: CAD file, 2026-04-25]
cad/Full Assembly - Electronics Cover.step
105.0 x 41.0 x 166.0 mm

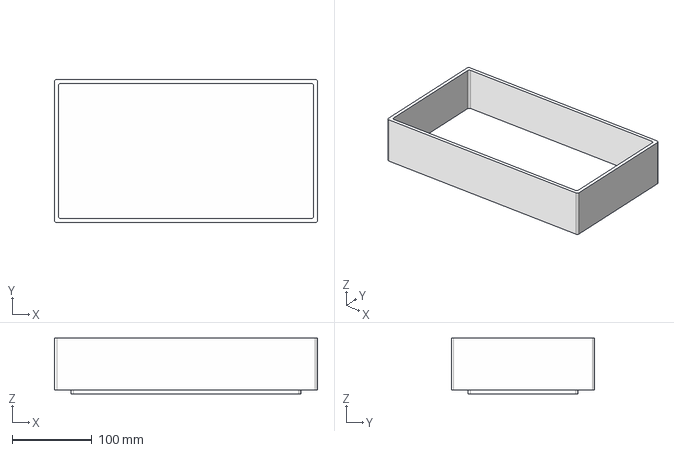
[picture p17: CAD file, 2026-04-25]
cad/Full Assembly - Bottom Tank.step
330.0 x 180.0 x 70.0 mm

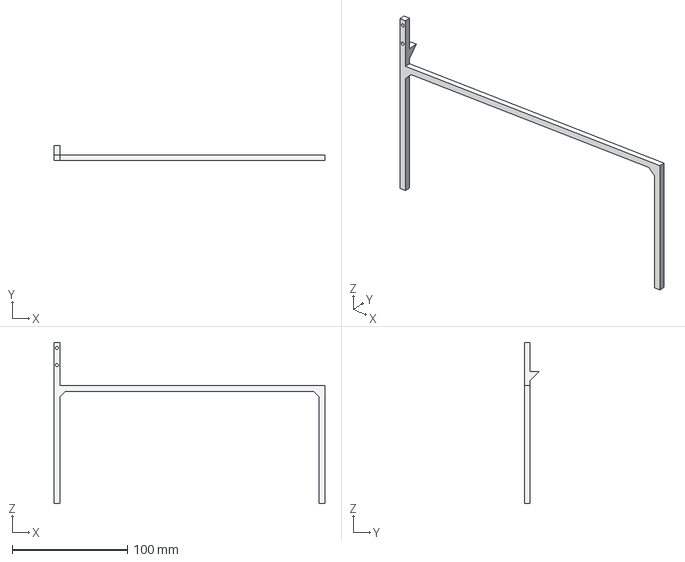
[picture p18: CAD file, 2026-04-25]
cad/Full Assembly - Surface Fork Holder.step
235.0 x 12.7 x 139.7 mm

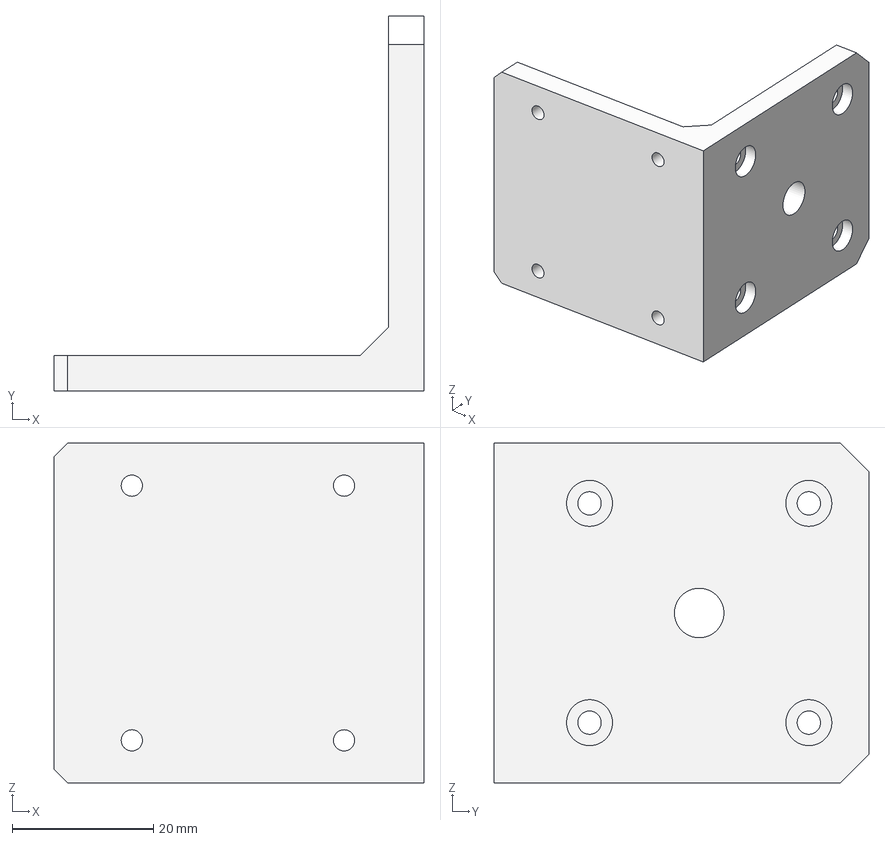
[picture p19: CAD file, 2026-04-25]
cad/Full Assembly - Motor Mount.step
52.3 x 53.0 x 48.0 mm

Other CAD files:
cad/Full Assembly - Rain Tank Holder 2.step

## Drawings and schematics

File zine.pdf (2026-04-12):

# Rainbox

### An ambient rain sound

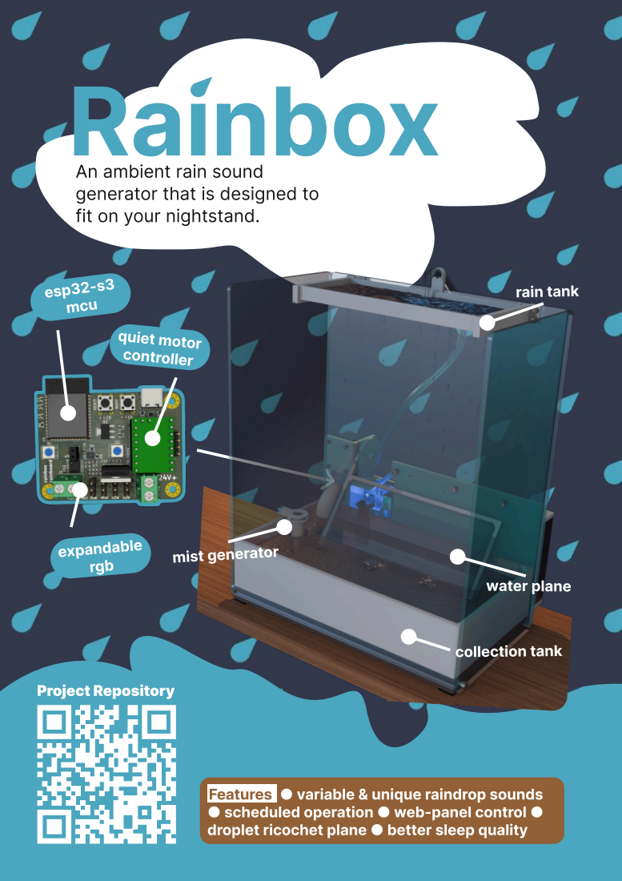
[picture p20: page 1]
esp32-s3; mcu; quiet motor; controller; rain tank; expandable; water plane; collection tank; Project Repository; Feature s; ● variable & unique raindrop sounds; Features

generator that is designed to

fit on your nightstand.

rgb mist generator

● scheduled operation ● web-panel control ●

droplet ricochet plane ● better sleep quality

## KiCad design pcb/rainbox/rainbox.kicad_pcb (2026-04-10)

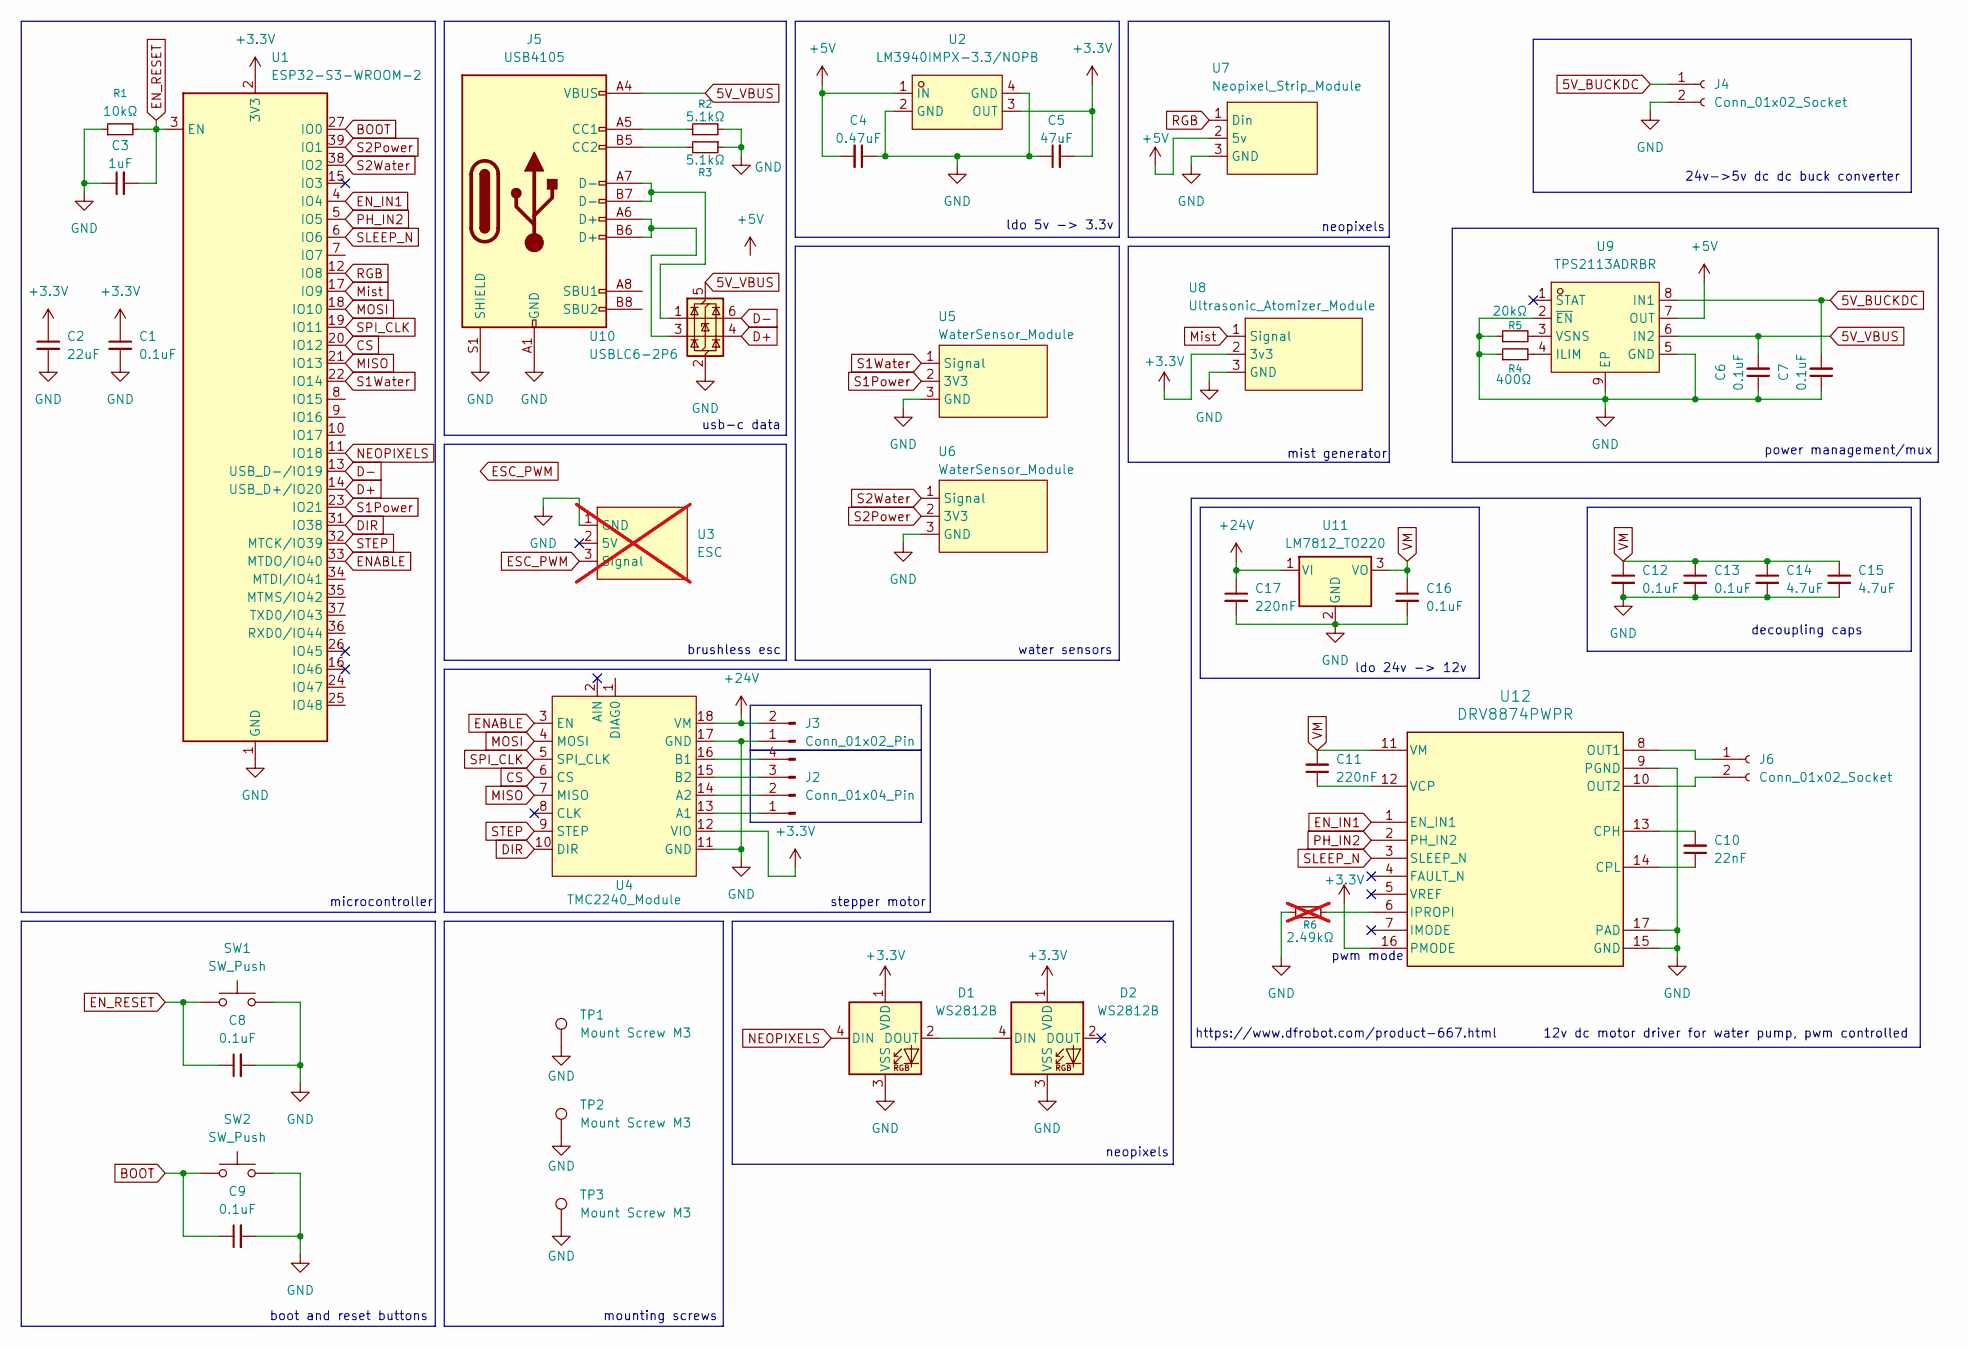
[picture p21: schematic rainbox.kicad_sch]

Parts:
C1, C6, C7, C8, C9, C12, C13, C16: 0.1uF; C_0603_1608Metric
C2: 22uF; C_0603_1608Metric
C3: 1uF; C_0603_1608Metric
C4: 0.47uF; C_0603_1608Metric
C5: 47uF; C_0603_1608Metric
C10: 22nF; C_0603_1608Metric
C11, C17: 220nF; C_0603_1608Metric
C14, C15: 4.7uF; C_0603_1608Metric
D1, D2: WS2812B; LED_WS2812B_PLCC4_5.0x5.0mm_P3.2mm
J2: Conn_01x04_Pin; PinHeader_1x04_P2.54mm_Vertical
J3: Conn_01x02_Pin; TerminalBlock_Phoenix_PT-1,5-2-5.0-H_1x02_P5.00mm_Horizontal
J4: Conn_01x02_Socket; PinSocket_1x02_P2.54mm_Vertical
J5: USB4105; USB_C_Receptacle_GCT_USB4105-xx-A_16P_TopMnt_Horizontal
J6: Conn_01x02_Socket; TerminalBlock_Phoenix_PT-1,5-2-5.0-H_1x02_P5.00mm_Horizontal
R1: 10kΩ; R_0603_1608Metric
R2, R3: 5.1kΩ; R_0603_1608Metric
R4: 400Ω; R_0603_1608Metric
R5: 20kΩ; R_0603_1608Metric
R6: 2.49kΩ; R_0603_1608Metric; not fitted
SW1, SW2: SW_Push; SW_PUSH_6mm
TP1, TP2, TP3: Mount Screw M3; MountingHole_3.2mm_M3_Pad_Via
U1: ESP32-S3-WROOM-2
U2: LM3940IMPX-3.3/NOPB; SOT-223-4_L6.5-W3.5-P2.30-LS7.0-BR; LCSC Part C544820
U3: ESC; PinHeader_1x03_P2.54mm_Vertical; not fitted
U4: TMC2240_Module; tmc2240_module
U5, U6: WaterSensor_Module; PinHeader_1x03_P2.54mm_Vertical
U7: Neopixel_Strip_Module; PinHeader_1x03_P2.54mm_Vertical
U8: Ultrasonic_Atomizer_Module; PinHeader_1x03_P2.54mm_Vertical
U9: TPS2113ADRBR; SON-8_L3.0-W3.0-P0.65-LS3.0-BL-EP; LCSC Part C354512
U10: USBLC6-2P6; SOT-666
U11: LM7812_TO220; TO-220-3_Vertical
U12: DRV8874PWPR; PWP0016J_N

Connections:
5V_BUCKDC: C7.2, J4.1, U9.8 (IN1)
5V_VBUS: C6.2, J5.A4 (VBUS), J5.A9 (VBUS), J5.B4 (VBUS), J5.B9 (VBUS), U9.6 (IN2), U10.5 (VBUS)
+3.3V: C1.1, C2.1, C5.2, D1.1 (VDD), D2.1 (VDD), U1.2 (3V3), U2.3 (OUT), U4.12 (VIO), U8.2 (3v3), U12.16 (PMODE)
+5V: C4.2, U2.1 (IN), U7.2 (5v), U9.7 (OUT)
+24V: C17.1, J3.2, U4.18 (VM), U11.1 (VI)
BOOT: C9.1, SW2.1, U1.27 (IO0)
CS: U1.20 (IO12), U4.6 (CS)
D+: U1.14 (USB_D+/IO20), U10.4 (I/O2)
D-: U1.13 (USB_D-/IO19), U10.6 (I/O1)
DIR: U1.31 (IO38), U4.10 (DIR)
ENABLE: U1.33 (MTDO/IO40), U4.3 (EN)
EN_IN1: U1.4 (IO4), U12.1 (EN_IN1)
EN_RESET: C3.2, C8.1, R1.2, SW1.1, U1.3 (EN)
GND: C1.2, C2.2, C3.1, C4.1, C5.1, C6.1, C7.1, C8.2, C9.2, C12.2, C13.2, C14.2, C15.2, C16.2, C17.2, D1.3 (VSS), D2.3 (VSS), J3.1, J4.2, J5.A1 (GND), J5.A12 (GND), J5.B1 (GND), J5.B12 (GND), J5.S1 (SHIELD), R1.1, R2.2, R3.1, R4.1, R5.1, R6.1, SW1.2, SW2.2, TP1.1, TP2.1, TP3.1, U1.1 (GND), U1.40 (GND), U1.41 (GND), U2.2 (GND), U2.4 (GND), U3.1 (GND), U4.11 (GND), U4.17 (GND), U5.3 (GND), U6.3 (GND), U7.3 (GND), U8.3 (GND), U9.2 (~EN), U9.5 (GND), U9.9 (EP), U10.2 (GND), U11.2 (GND), U12.9 (PGND), U12.15 (GND), U12.17 (PAD)
MISO: U1.21 (IO13), U4.7 (MISO)
MOSI: U1.18 (IO10), U4.4 (MOSI)
Mist: U1.17 (IO9), U8.1 (Signal)
NEOPIXELS: D1.4 (DIN), U1.11 (IO18)
unnamed: D1.2 (DOUT), D2.4 (DIN)
unnamed: J2.1, U4.13 (A1)
unnamed: J2.2, U4.14 (A2)
unnamed: J2.3, U4.15 (B2)
unnamed: J2.4, U4.16 (B1)
unnamed: J5.A5 (CC1), R2.1
unnamed: J5.B5 (CC2), R3.2
unnamed: J5.A6 (D+), J5.B6 (D+), U10.3 (I/O2)
unnamed: J5.A7 (D-), J5.B7 (D-), U10.1 (I/O1)
unnamed: J6.1, U12.8 (OUT1)
unnamed: J6.2, U12.10 (OUT2)
unnamed: R4.2, U9.4 (ILIM)
unnamed: R5.2, U9.3 (VSNS)
unnamed: C10.2, U12.13 (CPH)
unnamed: C10.1, U12.14 (CPL)
unnamed: R6.2, U12.6 (IPROPI)
unnamed: C11.1, U12.12 (VCP)
PH_IN2: U1.5 (IO5), U12.2 (PH_IN2)
RGB: U1.12 (IO8), U7.1 (Din)
S1Power: U1.23 (IO21), U5.2 (3V3)
S1Water: U1.22 (IO14), U5.1 (Signal)
S2Power: U1.39 (IO1), U6.2 (3V3)
S2Water: U1.38 (IO2), U6.1 (Signal)
SLEEP_N: U1.6 (IO6), U12.3 (SLEEP_N)
SPI_CLK: U1.19 (IO11), U4.5 (SPI_CLK)
STEP: U1.32 (MTCK/IO39), U4.9 (STEP)
VM: C11.2, C12.1, C13.1, C14.1, C15.1, C16.1, U11.3 (VO), U12.11 (VM)

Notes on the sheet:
stepper motor
usb-c data
https://www.dfrobot.com/product-667.html
24v->5v dc dc buck converter
brushless esc
mounting screws
ldo 5v -> 3.3v
neopixels
pwm mode
microcontroller
mist generator
boot and reset buttons
ldo 24v -> 12v
decoupling caps
12v dc motor driver for water pump, pwm controlled
water sensors
power management/mux

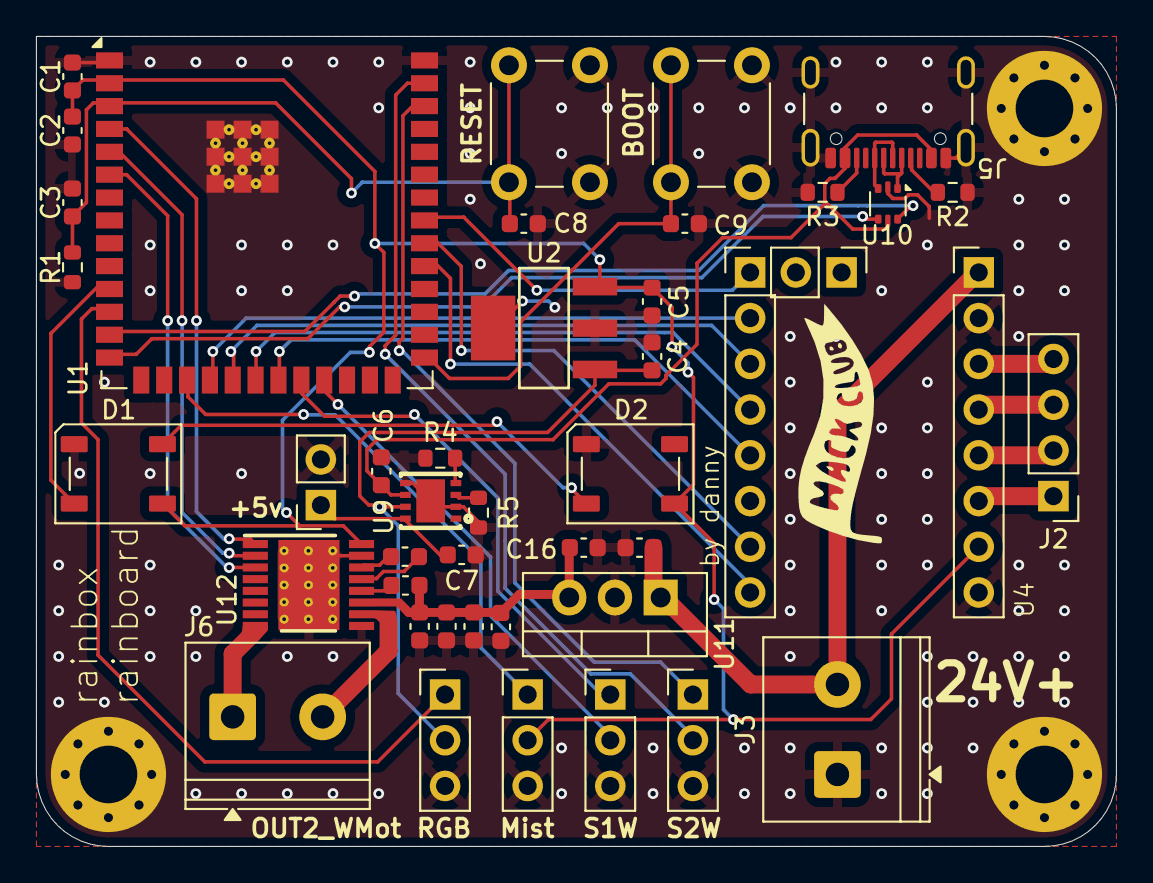
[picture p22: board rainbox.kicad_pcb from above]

Board: 2 copper layers, 60.0 x 45.0 mm, 45 parts (0 on the bottom side), 44 nets.

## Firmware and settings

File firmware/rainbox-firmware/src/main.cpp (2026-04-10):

#include <Arduino.h>
#include <FastLED.h>
#include <AsyncTCP.h>
#include <WiFi.h>

#include <ESPAsyncWebServer.h>

// neopixels
#define NEOPIXEL_BUILTIN  18
#define NUM_LEDS_BUILTIN  2

CRGB ledsB[NUM_LEDS_BUILTIN];

#define NEOPIXEL_STRIP    8
#define NUM_LEDS_STRIP    1 // change if you have one plugged in

CRGB ledsS[NUM_LEDS_STRIP];

// mist sensor
#define MIST_SENSOR       9

// water sensors
#define WATER_SENSOR_1    14
#define WATER_SENSOR_1PWR 21
#define WATER_SENSOR_2    2  // not used but convenient later if needed
#define WATER_SENSOR_2PWR 1
int water_level_1 = 0;
int water_level_2 = 0;

// water pump controller (DRV8874PWPR in PMODE)
#define WATER_EN_IN1      4
#define WATER_PH_IN2      5
#define WATER_SLEEP_N     6

// stepper controller
#define PLANE_DIR         38
#define PLANE_STEP        39
#define PLANE_ENABLE      40
#define PLANE_MOSI        10
#define PLANE_SPI_CLK     11
#define PLANE_CS          12
#define PLANE_MISO        13

boolean waterPlaneEnabled = true;

// wifi ap web server panel controller
static const char *htmlContent PROGMEM = R"(
<!DOCTYPE html>
<html>
  <head>
    <title>rainbox control panel</title>
  </head>
  <body>
    <h1>rainbox control panel</h1>

    <span>water level</span>
    <progress id="water level" value="0" max="533"> 32% </progress>

    <br />
    <br />

    <fieldset>
      <legend>Scheduling</legend>

      <div>
        <input type="checkbox" id="scheduled" name="scheduled" checked />
        <label for="scheduled">Active Schedule</label>
      </div>

      <div>
        <input
          type="time"
          id="time_start"
          name="time_start" />
        <label for="time_start">Start Time</label>
      </div>

      <div>
        <input
          type="time"
          id="time_end"
          name="time_end" />
        <label for="time_end">End Time</label>
      </div>

    </fieldset>

    <fieldset>
      <legend>Configuration</legend>

      <div>
        <input type="checkbox" id="rgb" name="rgb" checked />
        <label for="rgb">RGB Lights</label>
      </div>

      <div>
        <input type="checkbox" id="mist" name="mist" checked />
        <label for="mist">Mist</label>
      </div>

    </fieldset>

    <fieldset>
      <legend>Testing</legend>

      <div>
        <button onclick="sendMessage('tPump');">Enable Pump</button>
        <button onclick="sendMessage('fPump');">Disable Pump</button>
        <br />
        <button onclick="sendMessage('tWPlane');">Enable Water Plane</button>
        <button onclick="sendMessage('fWPlane');">Disable Water Plane</button>
        <br />
        <button onclick="sendMessage('tRGB');">Enable RGB</button>
        <button onclick="sendMessage('fRGB');">Disable RGB</button>
        <br />
        <button onclick="sendMessage('tMist');">Enable Mist</button>
        <button onclick="sendMessage('fMist');">Disable Mist</button>
      </div>

    </fieldset>
  </body>
  <script>
    var ws = new WebSocket('ws://192.168.4.1/ws');
    ws.onopen = function() {
      console.log("WebSocket connected");
    };
    ws.onclose = function() {
      console.log("WebSocket closed");
    };
    ws.onerror = function(error) {
      console.log("WebSocket error: " + error);
    };

    ws.onmessage = function(event) { // handle this <---------------------------
      console.log("WebSocket message: " + event.data);
    };

    function sendMessage(message) {
      console.log("WebSocket sent: " + message);
      ws.send(message);
    }
  </script>
</html>
)";
static const size_t htmlContentLength = strlen_P(htmlContent);

static AsyncWebServer server(80);
static AsyncWebSocket ws("/ws");

void setup() {
  Serial.begin(115200);
  
  // setup devices and ip
  FastLED.addLeds<NEOPIXEL, NEOPIXEL_BUILTIN>(ledsB, NUM_LEDS_BUILTIN);
  FastLED.addLeds<NEOPIXEL, NEOPIXEL_STRIP>(ledsS, NUM_LEDS_STRIP);

  pinMode(PLANE_DIR, OUTPUT);
  pinMode(PLANE_STEP, OUTPUT);
  pinMode(PLANE_ENABLE, OUTPUT);

  pinMode(MIST_SENSOR, OUTPUT);

  pinMode(WATER_EN_IN1, OUTPUT);
  pinMode(WATER_PH_IN2, OUTPUT);
  pinMode(WATER_SLEEP_N, OUTPUT);

  delayMicroseconds(500);

  // setup wifi connection for local webpanel
  #if ASYNCWEBSERVER_WIFI_SUPPORTED
    WiFi.mode(WIFI_AP);
    WiFi.softAP("esp-captive");
  #endif

  server.on("/", HTTP_GET, [](AsyncWebServerRequest *request) {
    request->send(200, "text/html", (uint8_t *)htmlContent, htmlContentLength);
  });

  ws.onEvent([](AsyncWebSocket *server, AsyncWebSocketClient *client, AwsEventType type, void *arg, uint8_t *data, size_t len) {
    (void)len;

    if (type == WS_EVT_CONNECT) {
      Serial.println("ws connect");
    } else if (type == WS_EVT_DISCONNECT) {
      Serial.println("ws disconnect");
    } else if (type == WS_EVT_ERROR) {
      Serial.println("ws error");
    } else if (type == WS_EVT_DATA) {
      AwsFrameInfo *info = (AwsFrameInfo *)arg;
      Serial.printf(
        "index: %" PRIu64 ", len: %" PRIu64 ", final: %" PRIu8 ", opcode: %" PRIu8 ", framelen: %d\n", info->index, info->len, info->final,
        info->message_opcode, len
      );

      //todo handling messages
    }
  });


  server.addHandler(&ws);
  server.begin();

  delayMicroseconds(500);







  // test mist for half a second
  digitalWrite(MIST_SENSOR, HIGH);
  delayMicroseconds(500);
  digitalWrite(MIST_SENSOR, LOW);
  delayMicroseconds(500);

  // test water sensor and neopixels
  for (int i = 0; i < 1200; i++) { // 30 seconds
    int mappedVal = map(readWaterLevel1(), 0, 533, 0, 255);
    ledsB[0] = CRGB(mappedVal, 255, 0);
    ledsB[1] = CRGB(mappedVal, 255, 0);
    FastLED.show();
    delayMicroseconds(25);
  }

  // test water plane (always starts in its enabled pos for reference)
  setWaterPlaneEnabled(false);
  delayMicroseconds(1000);
  setWaterPlaneEnabled(true);
  delayMicroseconds(1000);

  // test water pump
  digitalWrite(WATER_SLEEP_N, HIGH); //enable device
  delayMicroseconds(100);
  analogWrite(WATER_EN_IN1, 255); // swap en and ph if pump is going backwards
  digitalWrite(WATER_PH_IN2, LOW);
  delayMicroseconds(1000);
  digitalWrite(WATER_SLEEP_N, LOW); // coast and disable everything
  digitalWrite(WATER_EN_IN1, LOW);
  digitalWrite(WATER_PH_IN2, LOW);

}

void loop() {
  delay(100);
}

//https://www.blue-pcb.com/products/9b30000-rain-water-level-sensor-module-detection-liquid-surface-depth-height-for-arduino
// reads only periodically to avoid oxidization https://www.reddit.com/r/arduino/comments/5plgrm/comment/dcs22lp
int readWaterLevel1() { // between 0-533
  digitalWrite(WATER_SENSOR_1PWR, HIGH);
  delay(10);
  water_level_1 = analogRead(WATER_SENSOR_1);
  digitalWrite(WATER_SENSOR_1PWR, LOW);
  return water_level_1;
}

int readWaterLevel2() { // between 0-533
  digitalWrite(WATER_SENSOR_2PWR, HIGH);
  delay(10);
  water_level_2 = analogRead(WATER_SENSOR_2);
  digitalWrite(WATER_SENSOR_2PWR, LOW);
  return water_level_2;
}

void setWaterPlaneEnabled(boolean on) { // todo in prod: check direction + time needed
  if (on && !waterPlaneEnabled) {
    digitalWrite(PLANE_DIR, HIGH);
    digitalWrite(PLANE_STEP, HIGH);
  } else if (!on && waterPlaneEnabled) {
    digitalWrite(PLANE_DIR, LOW);
    digitalWrite(PLANE_STEP, HIGH);
  }

  delayMicroseconds(500);

  // turn off
  digitalWrite(PLANE_STEP, LOW);

  waterPlaneEnabled = on;
}

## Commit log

2026-03-20 add pcb and research
    [rainbox.kicad_pcb, rainbox.kicad_sch]
2026-03-21 more kicad additions and research
    [rainbox.kicad_sch]
2026-03-31 update pcb
    [rainbox.kicad_pcb, rainbox.kicad_sch]
2026-04-04 replace esc controller with dc motor ic
    [rainbox.kicad_pcb, rainbox.kicad_sch]
2026-04-06 pcb additions, readme, md stuff
    [bom-JLCPCB Assembly Order.xls, bom.csv, designators.csv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]
2026-04-06 fix bom link
2026-04-06 initial code
    [large_fat_32MB.csv]
2026-04-10 add prototype firmware + fix pcb
    [rainbox.kicad_pcb, rainbox.kicad_sch]
2026-04-12 add bom and renders
    [BOM.csv]
2026-04-24 add cad files
    [Full Assembly - Bottom Tank.step, Full Assembly - Electronics Cover.step, Full Assembly - Gear.step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]
2026-04-25 bom optimizations
    [BOM.csv]
2026-04-26 Modify BOM.csv with new parts and prices
    Updated BOM.csv to reflect changes in parts and pricing.
    [BOM.csv]
